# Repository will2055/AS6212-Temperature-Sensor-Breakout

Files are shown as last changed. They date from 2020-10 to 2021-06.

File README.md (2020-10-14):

# AS6212-Temperature-Sensor-Breakout
Hardware repository for the AMS AS6212 Temperature Sensor

### AMS AS6212 Temperature Sensor

The highest performing AS6212 has an accuracy of +/- 0.2°C from -10°C to 65 °C. It provides a resolution of 16 bit over the wide temperature range from -40°C to 125°C. The integrated alarm functionality enables micro-controller wake-up calls on defined temperature thresholds. An internal voltage regulator allows stable accuracy independent of the supply voltage between 1.71V to 3.6V. For power sensitive applications, the device can enter a low-power wait mode with 0.1μA current consumption.

Documentation
--------------
* **[Main Repository](https://github.com/will2055/AS6212-Temperature-Sensor-Breakout)** - Main repository (including hardware files) for the temperature sensor.
* **[Arduino Library](https://github.com/will2055/AS6212-Arduino-Library)** - Repository containing the Arduino library software to interface with this sensor.

License Information
-------------------

This project is _**open source**_! 

Please review the LICENSE.md file for license information
Distributed as-is; no warranty is given.

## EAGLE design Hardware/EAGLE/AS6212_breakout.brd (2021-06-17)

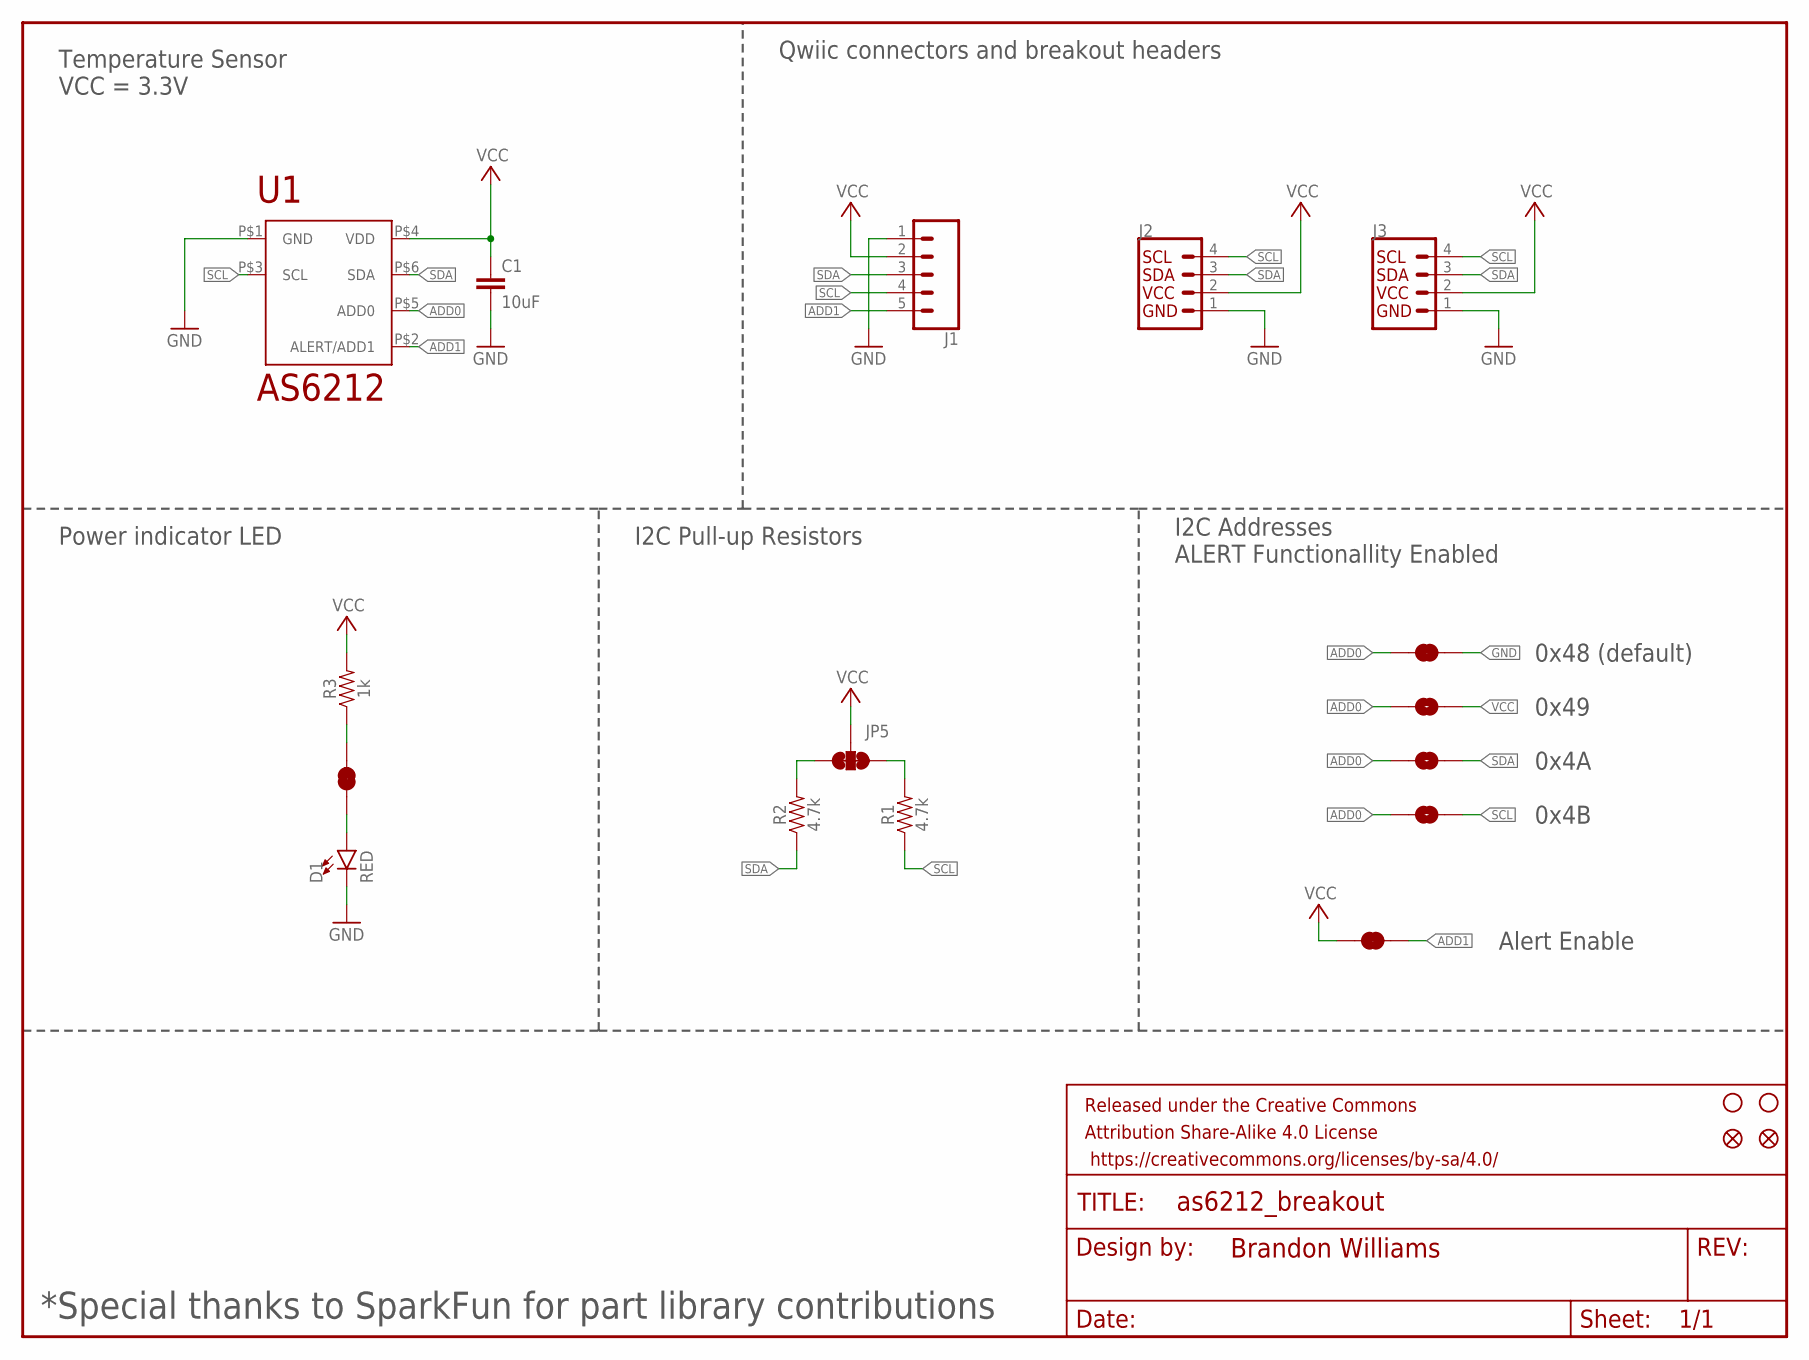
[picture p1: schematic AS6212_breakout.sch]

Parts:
C1: 10uF; 0805
D1: RED; LED-0603
FD1, FD2: FIDUCIAL0.2MM; FIDUCIAL-0.2MM
FRAME1: FRAME-LETTERNO_PACKAGE; DUMMY
H1, H2: STAND-OFF
J1: CONN_05; 1X05
J2, J3: QWIIC_RIGHT_ANGLE; JST04_1MM_RA
JP1, JP2, JP3: JUMPER-SMT_2_NO_SILK; SMT-JUMPER_2_NO_SILK
JP4, JP6, JP7: JUMPER-SMT_2_NC_TRACE_SILK; SMT-JUMPER_2_NC_TRACE_SILK
JP5: JUMPER-SMT_3_2-NC_TRACE_SILK; SMT-JUMPER_3_2-NC_TRACE_SILK
R1, R2: 4.7k; 0603
R3: 1k; 0603
U1: AS6212

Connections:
ADD0: JP1.1, JP2.1, JP3.1, JP4.1, U1.P$5 (ADD0)
ADD1: J1.5, JP6.2, U1.P$2 (ALERT/ADD1)
GND: C1.2, D1.C, J1.1, J2.1, J3.1, JP4.2, U1.P$1 (GND)
unnamed: JP5.3, R2.2
unnamed: JP5.1, R1.2
unnamed: JP7.2, R3.1
unnamed: D1.A, JP7.1
SCL: J1.4, J2.4, J3.4, JP2.2, R1.1, U1.P$3 (SCL)
SDA: J1.3, J2.3, J3.3, JP1.2, R2.1, U1.P$6 (SDA)
VCC: C1.1, J1.2, J2.2, J3.2, JP3.2, JP5.2, JP6.1, R3.2, U1.P$4 (VDD)

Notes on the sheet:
Temperature Sensor VCC = 3.3V
Qwiic connectors and breakout headers
Power indicator LED
I2C Pull-up Resistors
I2C Addresses ALERT Functionallity Enabled
0x48 (default)
0x49
0x4A
0x4B
Alert Enable
*Special thanks to SparkFun for part library contributions

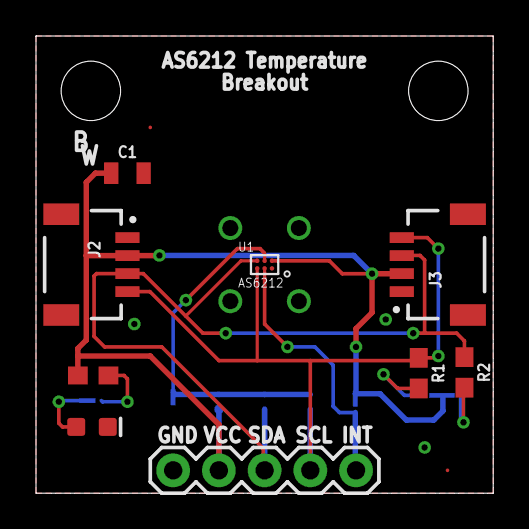
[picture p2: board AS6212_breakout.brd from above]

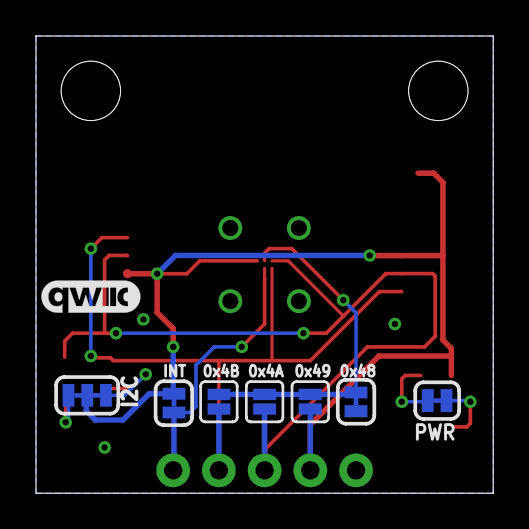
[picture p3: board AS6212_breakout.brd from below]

Board: 2 copper layers, 25.4 x 25.4 mm, 22 parts (8 on the bottom side), 10 nets.

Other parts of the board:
U$1: QWIIC_5.5MM

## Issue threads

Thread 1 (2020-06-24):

AS6212 Library footprints are swapped

will2055, 2020-06-24:
The pins are arranged from the "bottom" perspective and not the "top". Change for board revision.

will2055, 2020-06-24:
Fixed pin library issue. See new commit for details. Closing issue.

Closed 2020-06-24.

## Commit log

2020-06-16 Add EAGLE files via upload
    [AS6212_breakout.brd, AS6212_breakout.sch]
2020-06-17 Verify Github Upload
    [AS6212_breakout.brd, AS6212_breakout.sch]
2020-06-17 minor schematic changes to EAGLE files
2020-06-24 fixed pin layout issue
    pins were swapped, moved to right locations
2020-06-26 Board Layout Revision
    Changing board features for new footprint library
2020-07-22 v01 main push
    Updated Eagle files and source software
    [AS6212_breakout.brd, AS6212_breakout.sch]
2020-07-29 Rev 02 push
    First production version of breakout board - push ready
    [AS6212_breakout.brd, AS6212_breakout.sch]
2020-07-31 Configuration register updates
    small changes to software and hardware.
    [AS6212_breakout.brd, AS6212_breakout.sch]
2020-08-14 JLCPCB Tolerances
    updates design rules for minimum JLCPCB specs
    [AS6212_breakout.brd]
2020-09-16 Bug fixes
    Added thank you in schematic as well
    [AS6212_breakout.sch]
2021-06-17 Board design rework & datasheet upload
    [AS6212_breakout.brd, AS6212_breakout.sch]

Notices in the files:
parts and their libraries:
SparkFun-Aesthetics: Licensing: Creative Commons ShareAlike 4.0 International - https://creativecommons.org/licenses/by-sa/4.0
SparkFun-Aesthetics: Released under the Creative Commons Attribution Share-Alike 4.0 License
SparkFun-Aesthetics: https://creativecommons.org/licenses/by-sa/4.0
